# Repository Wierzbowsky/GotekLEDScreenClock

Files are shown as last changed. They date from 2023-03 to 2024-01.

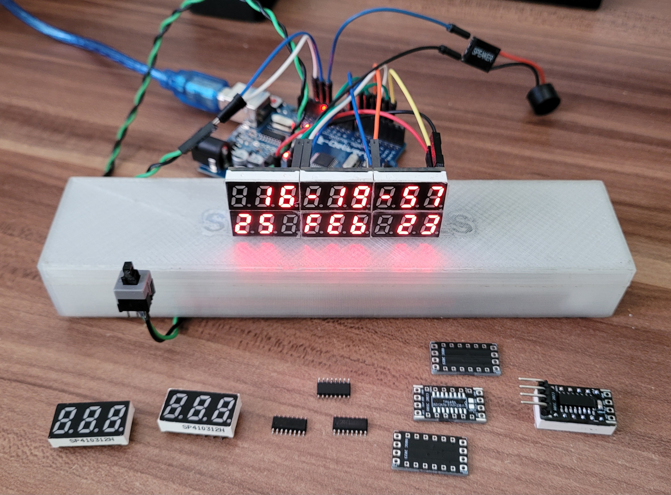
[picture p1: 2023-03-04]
Pics/20230225_162103.jpg

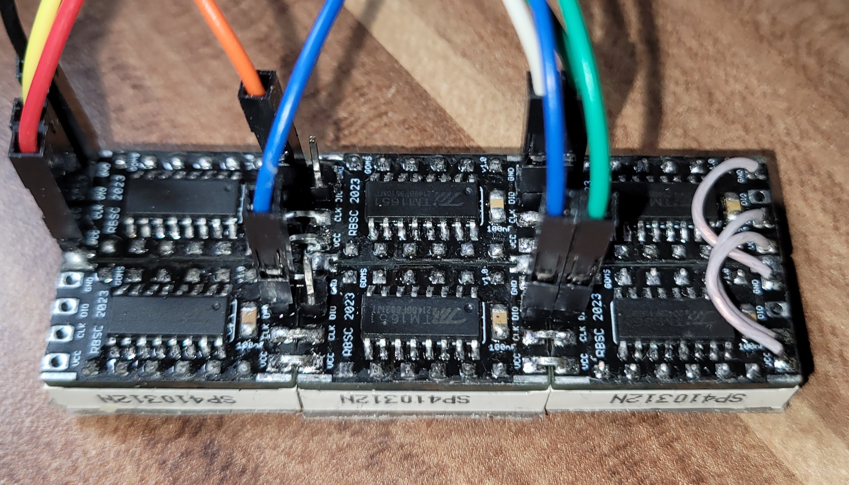
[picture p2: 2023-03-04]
Pics/20230304_183644.jpg

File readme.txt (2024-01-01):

--------------------------------------------------------------------------------
Clock with calendar from Gotek's LED screen parts
Copyright (c) 2022-2023 Wierzbowsky [RBSC]
Version 1.0.0006
--------------------------------------------------------------------------------

About
-----

This is the the self-made clock that was created from salvaged Gotek's 7-segment LED screen boards. The original Gotek
screen boards need to be dismantled and all parts (IC, screen, capacitor) are used to create a single or combined
indicator panel with the help of tiny circuit boards that can be joined together. These boards share all signals except
for DIO. Each DIO pin is connected to the corresponding pin of the Arduino Mini, Nano or Uno board. This particular clock
has 6 screens joined together.

The screens can display decimal and hexadecimal numbers with or without prepending zeroes, single digits and characters
at defined positions, all Latin alphabet and also several special characters (minus, plus, slash, etc). The original
Arduino library for the TM1651 chip created by Derek Cooper was almost completely rewritten and enriched with features.
A few subroutines from the library were imported into the .INO file to make things easier.

The Arduino board with the custom self-made firmware allows to set the time and date, select 3 brightness levels and also
to enable the auto-brightness mode. A user can enable the hourly beep during day hours and set the adjustment to slow
down or make the clock run faster. The total consumption of the clock with Arduino board is around 100mA, so powering it
up from a USB2 port is fine.

Assembling
----------

Take 6 orginal Gotek LED screen boards and desolder the LED screen, the controller chip and the capacitor. Then solder the
chip, capacitor and the screen onto the small board (you can order it from jlcpcb.com factory using the provided Gerber
files).

Solder a 4-pin single row header to the right side of one assembled board. To make it easier, it's recommended to solder
the 4-pin header BEFORE soldering the screen. Cut the popping out pins of the pin header from the other side so that the
screen could be fully set onto the board.

Assemble the 2-row 3-column display from the 6 complete boards. Make sure that there's no gap between the screens. To join
the boards you can use U shaped pins cut from the pin headers. See the picture of the assembled screen for reference.

Connect power, ground and clock lines of each screens in a row together. Solder 3 wires between corresponding solder pads
of power, ground and clock signals of the upper row and the bottom row. See the picture of the assembled screen.

Finally, solder four 2-pin headers onto the DIO solder pads of each board. 

Connections
-----------

Connect each board's DIO pin to the digitap I/O pin of the Arduino Uno or Nano board. Please note thet the board has DIO
pads on each side, so please connect only ONE of them (one DIO signal for each screen). Connecting the DIO pins should be
done in the specific order so that the pin the the smallest number is connected to the leftmost screen.

In my setup the DIO pins are connected to the Arduino board the following way:

-------------------------
|---3---|---4---|---5---|
-------------------------
|---6---|---7---|---8---|
-------------------------

Connect the 3.3v power from the Arduino board to the 4-pin header's VCC pin. Connect the ground from the Arduino board to
the 4-pin header's GND pin. Connect the I/O pin 3 from the Arduino board to the 4-pin header's CLK pin (this is clock
signal). You can change the pin assignment in the source files if you wish. The current pin assignment is as follows:

Arduino		Clock board or beeper/button
--------------------------------------------
3.3v		VCC
GND		GND
 2		CLK
 3		DIO pin of screen 1
 4		DIO pin of screen 2
 5		DIO pin of screen 3
 6		DIO pin of screen 4
 7		DIO pin of screen 5
 8		DIO pin of screen 6
12		Beeper (optional)
13		Button
GND		Beeper's ground
GND             Button's ground

The piezo beeper is optional, but recommended. You can use a simple 2-pin beeper in a barrel-shaped case. It can be found
anywhere on AliExpress or Ebay. For example: https://www.ebay.com/itm/374210416844

Operation
---------

The clock is controlled by a single pushbutton. There are 3 types of commands that you can execute. A short pushdown (less
than 1 second push), a medium pushdown (over 1 second push) and a long pushdown (over 2 second push). It's all about timing.
Each operation is acknowledged by the clock with a beep of different frequency and duration if beep is enabled.

When the clock shows date and time, a short pushdown will change the brightness mode and disable the auto-brightness mode if
if was previously set. There are 3 different brightness levels to select manually. The auto-brightness uses only the dimmest
and the brightest levels.

The medium pushdown will allow to enter the settings mode (see below). The long pushdown switches on the auto-brightness
mode. The brightness will automatically change based on time of the day. From 8:00 to 20:00 high brightness is set,
otherwise low brightness is set.

The settings option can be selected by holding the pushbutton for over 1 second. In the settings mode a short pushdown will
change the value of hour, minute, second (reset to zero), day, month, year, select beep ON or beep OFF, select auto-brightness
ON of OFF, as well as allow to set the clock speed adjustment in the range of -15 to 15 (slow/fast). A short pushdown will
zero the value of seconds if seconds are blinking, for other values it will either switch them between ON or OFF or advance
the setting by 1. The medium pushdown will allow to select the setting that needs to be changed (hour, minute, day, etc.).
The currently selected value will blink. The selection is done in a loop, for example: second->minute->hour->second. The long
pushdown will switch to the next setup screen. That last screen of the setup will ask to press a button to start the clock
with the selected settings. The following setup screens are available in version 1.0.0005:

-> Set time -> Set date -> Set auto-brightness -> Set beep -> Set adjust -> Start clock

It may be tricky to change settings for the first time, but you will get used to it pretty fast.

Operation and test videos
-------------------------

You can see the videos of the clock's testing on Youtube:

 - https://www.youtube.com/watch?v=1-ujJE8o4cY
 - https://www.youtube.com/watch?v=EFognT4_trQ

IMPORTANT!
----------

I provide all files and information for free, without any liability (see the disclaimer.txt file). The provided information,
software or hardware must not be used for commercial purposes unless permitted by the owner. Producing a small amount of
bare boards for personal projects and selling the rest of the batch is allowed without the permission.

When the sources files are used to create alternative projects, please always mention the original source and the copyright!

Contact information
-------------------

The members of RBSC group Tnt23, Wierzbowsky, Pyhesty, Ptero, GreyWolf, SuperMax, VWarlock and DJS3000 can be contacted via the group's e-mail
address:

info@rbsc.su

The group's coordinator could be reached via this e-mail address:

admin@rbsc.su

The group's website can be found here:

https://rbsc.su/
https://rbsc.su/ru

The RBSC's hardware repository can be found here:

https://github.com/rbsc

The RBSC's 3D model repository can be found here:

https://www.thingiverse.com/groups/rbsc/things

-= ! MSX FOREVER ! =-

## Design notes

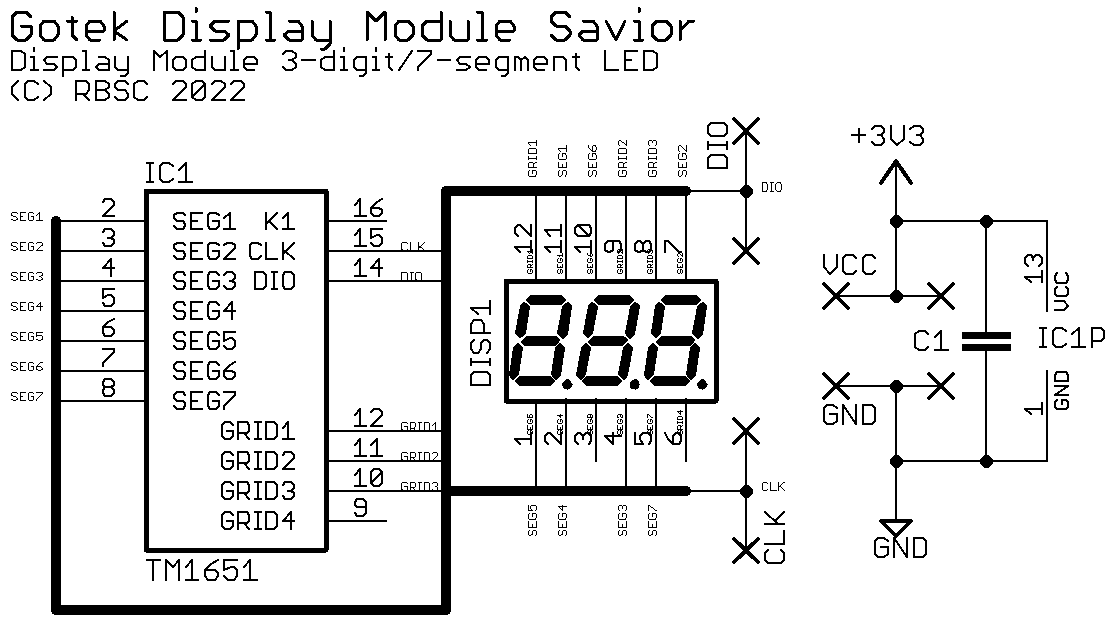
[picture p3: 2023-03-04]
Docs/schematics.png

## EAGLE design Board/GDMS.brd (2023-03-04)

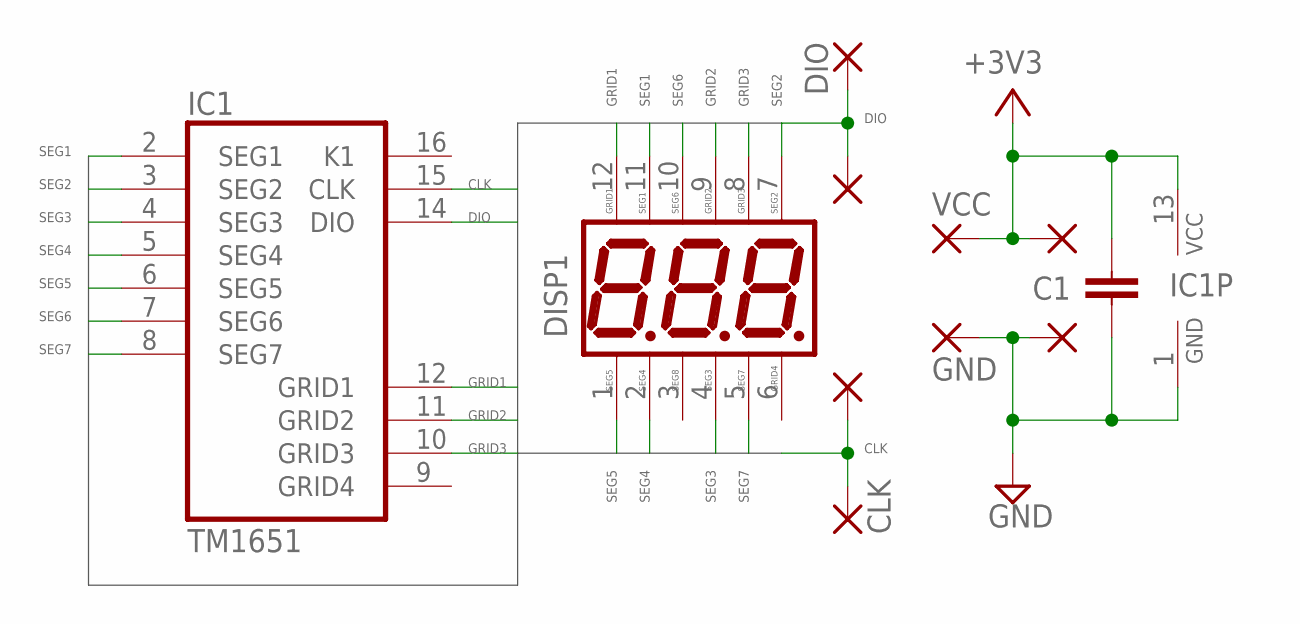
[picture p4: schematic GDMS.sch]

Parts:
C1: 100nF; C0805
DIS1: SP410312N; 3D7SEG
IC1: TM1651; SO16
P1: VCC; PADTH
P2, P4, P8, P9: PADTH
P3: GND; PADTH
P7: CLK; PADTH
P10: DIO; PADTH

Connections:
+3V3: C1.1, IC1.13 (VCC), P1.1, P2.1
CLK: IC1.15 (CLK), P7.1, P8.1
DIO: IC1.14 (DIO), P9.1, P10.1
GND: C1.2, IC1.1 (GND), P3.1, P4.1
GRID1: DIS1.12 (GRID1), IC1.12 (GRID1)
GRID2: DIS1.9 (GRID2), IC1.11 (GRID2)
GRID3: DIS1.8 (GRID3), IC1.10 (GRID3)
SEG1: DIS1.11 (SEG1), IC1.2 (SEG1)
SEG2: DIS1.7 (SEG2), IC1.3 (SEG2)
SEG3: DIS1.4 (SEG3), IC1.4 (SEG3)
SEG4: DIS1.2 (SEG4), IC1.5 (SEG4)
SEG5: DIS1.1 (SEG5), IC1.6 (SEG5)
SEG6: DIS1.10 (SEG6), IC1.7 (SEG6)
SEG7: DIS1.5 (SEG7), IC1.8 (SEG7)

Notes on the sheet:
DISP1

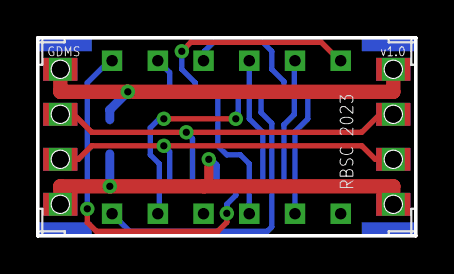
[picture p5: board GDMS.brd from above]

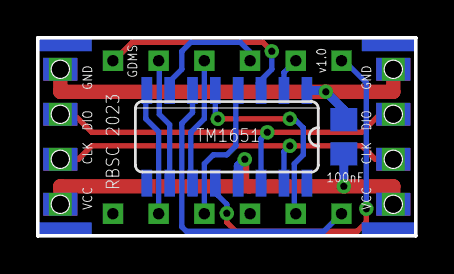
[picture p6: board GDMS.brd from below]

Board: 2 copper layers, 21.0 x 11.0 mm, 11 parts (2 on the bottom side), 14 nets.

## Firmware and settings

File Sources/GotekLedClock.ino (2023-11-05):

//****************************************************************
// GOCLOCK (Gotek Clock)
// Clock/calendar based on salvaged Gotek LED board with TM1651 chip
//
// Author:	  Alex Wierzbowsky
// Mail:	  	wierzbowsky@rbsc.su
// Hardware:	Re-used Gotek 3-digit LED screens on custom boards
// Board:   	Arduino Nano
// IDE:       Arduino
// Function:	Clock and calendar
// Date:		  06.11.2023
// Version:   1.0 Build 0007
// IDE:       Arduino-2.2.1
//
// Portions:  Paul Brace - Feb 2021
//
// Portions:  Detlef Giessmann Germany 
// Mail:      derek_cooper@hotmail.com
// Comment:   Library to drive LEDC68 Gotek 3 digit LED display
// IDE:       Arduino-1.8.12
//
//****************************************************************

//#include <SoftwareSerial.h>
//#include <Wire.h>
#include "GotekSaver.h"

// Define pins
#define Btnpin 10   // button pin
#define Buzzpin 9   // buzzer pin
#define Clockpin 2  // clock pin
#define Maxchars 9  // max characters on a display
#define Dispchars 3 // width of display

// Variables
uint8_t hour;
uint8_t minute;
uint8_t second;
uint8_t millisecond;
uint8_t date;
uint8_t month;
uint8_t year;
uint8_t currentbrt, changebrt;      // Brightness and change brightness control
uint8_t beep;
uint8_t autobrt;
signed long adjust;                 // ADJUST for inaccurate Arduino's clock, multiplied and added/deducted every minute
signed long multiplier;             // MULTIPLIER for clock adjust
volatile unsigned long currentTime, currentMode;     // Duration in milliseconds from midnight; currentMode: 1 when time/date is set; 0 - clock is running
unsigned long elapsed, timer;
unsigned long pushdelay;
char buffer[Maxchars+2];


//******************************************
// Setup
//
void setup()
{
// Set up time interrupt - millis() rolls over after 50 days so
// we are using our own millisecond counter which we can reset at
// the end of each day
 TCCR0A = (1 << WGM01);        //Set the CTC mode Compare time and trigger interrupt
 OCR0A = 0xF9;                 //Set value for time to compare to ORC0A for 1ms = 249  (8 bits so max is 256)
//[(Clock speed/Prescaler value)*Time   in seconds] - 1
//[(16,000,000/64) * .001] - 1 = 249 = 1 millisecond
 TIMSK0   |= (1 << OCIE0A);    //set timer compare interrupt
 TCCR0B |= (1 << CS01);        //Set the prescale 1/64 clock
 TCCR0B |= (1 << CS00);        // ie 110 for last 3 bits
 TCNT0  = 0;                   //initialize counter value to 0
 sei();                        //Enable   interrupt

 pinMode(Clockpin,OUTPUT);
 pinMode(Buzzpin,OUTPUT);
 pinMode(Btnpin,INPUT_PULLUP);

 for(Datapin = 3; Datapin < 9; Datapin++)
 {
  pinMode(Datapin,OUTPUT);
  displayOn();
  displaySet(currentbrt);
 }

 // Defaults
 hour=0;
 minute=0;
 second=0;

 date=06;
 month=11;
 year=23;

 // Variables
 multiplier = 10;
 pushdelay = 0;
 currentMode = 0;
 beep = 0;
 autobrt = 0;
 adjust = 0;
 currentbrt = 0;
 changebrt = 0;
 
 // Print version
 sprintf(buffer, " GOCLOCK ");
 Datapin = 5;
 PrintLine();
 sprintf(buffer, " 1-0 0007");
 Datapin = 8;
 PrintLine();
 //delay(3000);

 timer = currentTime;
 while(1)
 {
  elapsed = currentTime - timer;
  if (elapsed >= 3000) break;
 }

 for (Datapin = 4; Datapin < 9; Datapin++) displayClear();
 DisplayTime();
 DisplayDate();
 timer = currentTime = 0;
 currentMode = 0;
 interrupts();
}

//******************************************
//
// This is interrupt is called when   the compare time has been reached
// hence will be called once a millisecond   based on the
// OCR0A register setting.
ISR(TIMER0_COMPA_vect) {
  if (!currentMode) currentTime++;
}


//******************************************
// MAIN LOOP
//
void loop()
{
 int result;

 // Main control loop
 timer = currentTime;
 while(1)
 {
  elapsed = currentTime - timer;
  if (elapsed >= 1000)
  {
   timer = currentTime;
   ClockTick();       // Once per second
   DisplayTime();
   DisplayDate();
  }

  delay(50);
  if (result = ButtonCheck())
  {
   switch(result)
   {
    case 1:
    {
     autobrt = 0;
     changebrt = 0;
     if (beep) tone(Buzzpin,3000,100);
     if (currentbrt == 7) currentbrt = 0;
     else if (currentbrt == 0) currentbrt = 2;
     else if (currentbrt == 2) currentbrt = 7;
     for(Datapin = 3; Datapin < 9; Datapin++) displaySet(currentbrt);
     DisplayTime();
     DisplayDate();
     break;
    }
    case 2:
    {
     if (beep) tone(Buzzpin,3000,250);
     MainSetup();
     break;
    }
    case 3:
    {
     if (beep) tone(Buzzpin,5000,100);
     autobrt = 1;                       // Auto-control brightness
     changebrt = 1;
     break;
    }
    default:
     break;
   }
  }
 }
}

//******************************************
// Main setup
//
void MainSetup(void)
{
 uint16_t cnt;
 uint8_t shift;
 uint8_t param = 0;
 uint8_t set = 0;
 int result;
 uint8_t leapyear=0;

 // Adjust time
 Datapin=4;
 displaySpChar(0,Space);
 Datapin=5;
 displaySpChar(0,Space);
 
 sprintf(buffer, " SET TIME");
 Datapin = 8;
 PrintLine();
 Datapin=4;
 displaySpChar(0,Space);
 Datapin=5;
 displaySpChar(0,Space);

 param = 0;
 Datapin = 5;
 cnt = 0;
 while(!set)
 {
  delay(100);
  if (result = ButtonCheck())
  {
   switch(result)
   {
    case 1:
    {
     if (beep) tone(Buzzpin,3000,50);
     if (!param) second = 0;
     else if (param == 1)
     {
      minute++;
      if (minute == 60) minute = 0;
     }
     else if (param == 2)
     {
      hour++;
      if (hour == 24) hour = 0;
     }
     cnt = 1000;
     break;
    }
    case 2:
    {
     if (beep) tone(Buzzpin,3000,150);
     param++;
     if (param > 2) param = 0;
     cnt = 1000;
     break;
    }
    case 3:
    {
     if (beep) tone(Buzzpin,3000,250);
     set = 1;
     break;
    }    
   }
  }
  cnt++;
  if (cnt == 500)
  {
   Datapin = 5 - param;
   displayClear();
  }
  else if (cnt >= 1000)
  {
   DisplayTime();
   cnt = 0;
  }
 }
 DisplayTime();
 DisplayDate();

 // Adjust date
 sprintf(buffer, " SET DATE");
 Datapin = 5;
 PrintLine();

 param = 0;
 Datapin = 8;
 cnt = 0;
 set = 0;
 while(!set)
 {
  delay(100);
  if (result = ButtonCheck())
  {
   switch(result)
   {
    case 1:
    {
     if (beep) tone(Buzzpin,3000,50);
     if (!param)
     {
      year++;
      if (year > 50) year = 20;
     }
     else if (param == 1)
     {
      month++;
      if (month == 13) month = 1;
     }
     else if (param == 2)
     {
      if (year%4==0 and ((year%400==0) or (year%100!=0))) leapyear=1;
      if ((month==4 or month==6 or month==9 or month==11) and date==30) date=1;
      else if (month==2 and ((leapyear==0 and date==28) or (leapyear==1 and date==29))) date=1;
      else date++;
      if (date==32) date=1;
     }
     cnt = 1000;
     break;
    }
    case 2:
    {
     if (beep) tone(Buzzpin,3000,150);
     param++;
     if (param > 2) param = 0;
     cnt = 1000;
     break;
    }
    case 3:
    {
     if (beep) tone(Buzzpin,3000,250);
     set = 1;
     break;
    }    
   }
  }
  cnt++;
  if (cnt == 500)
  {
   Datapin = 8 - param;
   displayClear();
  }
  else if (cnt >= 1000)
  {
   DisplayDate();
   cnt = 0;
  }
 }

 // Auto brightness
 sprintf(buffer, " AUTO BRT");
 Datapin = 5;
 PrintLine();
 if (autobrt) sprintf(buffer, "       ON");
 else sprintf(buffer, "      OFF");
 Datapin = 8;
 PrintLine(); 

 cnt = 0;
 set = 0;
 while(!set)
 {
  delay(100);
  if (result = ButtonCheck())
  {
   switch(result)
   {
    case 1:
    {
     if (beep) tone(Buzzpin,3000,50);
     if (!autobrt) autobrt = 1;
     else autobrt = 0;
     cnt = 1000;     
     break;
    }
    case 3:
    {
     if (beep) tone(Buzzpin,3000,250);
     set = 1;
     break;
    }    
   }
  }
  cnt++;
  if (cnt == 500)
  {
   Datapin = 8;
   displayClear();
  }
  else if (cnt >= 1000)
  {
   if (autobrt) sprintf(buffer, "       ON");
   else sprintf(buffer, "      OFF");
   Datapin = 8;
   PrintLine(); 
   cnt = 0;
  }
 }

 // Adjust beep
 sprintf(buffer, " SET BEEP");
 Datapin = 5;
 PrintLine();
 if (beep) sprintf(buffer, "       ON");
 else sprintf(buffer, "      OFF");
 Datapin = 8;
 PrintLine(); 
 
 cnt = 0;
 set = 0;
 while(!set)
 {
  delay(100);
  if (result = ButtonCheck())
  {
   switch(result)
   {
    case 1:
    {
     if (beep) tone(Buzzpin,3000,50);
     if (!beep) beep = 1;
     else beep = 0;
     cnt = 1000;     
     break;
    }
    case 3:
    {
     if (beep) tone(Buzzpin,3000,250);
     set = 1;
     break;
    }    
   }
  }
  cnt++;
  if (cnt == 500)
  {
   Datapin = 8;
   displayClear();
  }
  else if (cnt >= 1000)
  {
   if (beep) sprintf(buffer, "       ON");
   else sprintf(buffer, "      OFF");
   Datapin = 8;
   PrintLine(); 
   cnt = 0;
  }
 }
 
 // Set adjust
 sprintf(buffer, "   ADJUST");
 Datapin = 5;
 PrintLine();
 if (adjust >= 0) sprintf(buffer, "      %03d", adjust);
 else sprintf(buffer, "     -%03d", adjust);
 Datapin = 8;
 PrintLine(); 
 
 cnt = 0;
 set = 0;
 while(!set)
 {
  delay(100);
  if (result = ButtonCheck())
  {
   switch(result)
   {
    case 1:
    {
     currentMode = 1; // stop count
     if (beep) tone(Buzzpin,3000,50);
     adjust++;
     if (adjust > 15) adjust = -15;
     cnt = 1000;
     currentMode = 0; // resume count
     break;
    }
    case 3:
    {
     if (beep) tone(Buzzpin,3000,250);
     set = 1;
     break;
    }    
   }
  }
  cnt++;
  if (cnt == 500)
  {
   Datapin = 8;
   displayClear();
  }
  else if (cnt >= 1000)
  {
   if (adjust >= 0) sprintf(buffer, "      %03d", adjust);
   else sprintf(buffer, "     -%03d", abs(adjust));
   Datapin = 8;
   PrintLine(); 
   cnt = 0;
  }
 }

 // Press button to start clock
 sprintf(buffer, "    PRESS");
 Datapin = 5;
 PrintLine();
 sprintf(buffer, " TO START");
 Datapin = 8;
 PrintLine();

 cnt = 0;
 set = 0;
 while(!set)
 {
  delay(100);
  if (result = ButtonCheck())
  {
    break;
  }
  cnt++;
  if (cnt == 500)
  {
    for (Datapin = 4; Datapin < 9; Datapin++) displayClear();
  }
  else if (cnt >= 1000)
  {
    sprintf(buffer, "    PRESS");
    Datapin = 5;
    PrintLine();
    sprintf(buffer, " TO START");
    Datapin = 8;
    PrintLine();
    cnt = 0;
  }
 }
 timer = currentTime = 0; 
 currentMode = 0; // Normal mode
 DisplayTime();
 DisplayDate();
 if (beep) tone(Buzzpin,5000,100);
}


//******************************************
// Prints a text line on a display from buffer
// Set Datapin for rightmost screen's pin number
//
void PrintLine()
{
 uint16_t cnt;
 uint8_t shift;

 shift = Maxchars-1;
 for(cnt = 0; cnt < Dispchars; cnt++)
 {
  displayChar(0, buffer[shift-2]);
  displayChar(1, buffer[shift-1]);
  displayChar(2, buffer[shift]);
  Datapin--;
  shift = shift - Dispchars;
 }
}

//******************************************
// Display time
//
void DisplayTime()
{
 uint8_t cnt;
 uint8_t shift;

 sprintf(buffer, " %02d %02d %02d",hour,minute,second);
 Datapin = 5;
 PrintLine();

 // Pulse dashes in clock
 if (second%2)
 {
  Datapin=4;
  displaySpChar(0,Minus);
  Datapin=5;
  displaySpChar(0,Minus);
 }
 else
 {
  Datapin=4;
  displaySpChar(0,Space);
  Datapin=5;
  displaySpChar(0,Space);
 }
}

//******************************************
// Display date
//
void DisplayDate()
{
 char monthname[4];
 uint8_t cnt;
 uint8_t shift;

 for(cnt = 0; cnt < 3; cnt++) monthname[cnt] = MonthTab[cnt + ((month - 1) * 3)];
 monthname[3] = '\0';
 if (date > 9) sprintf(buffer, "%02d %s %02d",date,monthname,year);
 else sprintf(buffer, " %d %s %02d",date,monthname,year);
 Datapin = 8;
 PrintLine();
}

//******************************************
// Checks for keypress (short, long, very long)
//
int ButtonCheck(void)
{
 if (digitalRead(Btnpin) == LOW) pushdelay++;
 if (pushdelay > 0 and digitalRead(Btnpin) == HIGH)
 {
  if ((pushdelay <= 500))
  {
    pushdelay = 0;
    return 1; // short press
  }
  else if (pushdelay <= 1000)
  {
    pushdelay = 0;
    return 2;  // long press
  }
  else if (pushdelay <= 3000)
  {
    pushdelay = 0;
    return 3;  // very long press
  }
  else
  {
   pushdelay = 0;
   return 0;
  }
 }
 else return 0;
}

//******************************************
// Clock adjust every hour
//
void ClockAdjust()
{
  if (adjust != 0)
  {
    currentMode = 1;
    if (adjust < 0)
    {
      if (currentTime >= abs(adjust) * multiplier) currentTime = currentTime - abs(adjust) * multiplier;
      else delay(abs(adjust) * multiplier);
    }
    else if (adjust > 0) currentTime = currentTime + abs(adjust) * multiplier;
    currentMode = 0;
  }
}

//******************************************
// Clock tick (every 1000ms)
//
void ClockTick()
{
 // Clock advance by 1 second
 second++;
 if (second==60)
 {
  second=0;
  minute++;
  ClockAdjust();    // Adjust clock every defined interval

  // Check if auto-brightness mode is on
  if (autobrt and changebrt)
  {
   for(Datapin = 3; Datapin < 9; Datapin++)
   {
    if (hour > 9 and hour < 18)
    {
     currentbrt = 7;
     displaySet(currentbrt);
    }
    else
    {
     currentbrt = 0;
     displaySet(currentbrt);
    }
   }
   changebrt = 0;
  }
  
  if (minute==60)
  {
   minute=0;
   hour++;
   if (beep and (hour >= 8 and hour <= 20)) tone(Buzzpin,3000,50); // beep every hour during daytime if on
   if (hour==24)
   {
     hour=0;
     currentMode = 1;
     timer = currentTime = 0; // Reset counter daily
     currentMode = 0;
     DateTick();
   }
  }
 }
}

//******************************************
// Date tick (every 24h)
//
void DateTick()
{
 uint8_t leapyear=0;
 
 if (year%4==0 and ((year%400==0) or (year%100!=0))) leapyear=1;
 if ((month==4 or month==6 or month==9 or month==11) and date==30)
 {
  date=1;
  month++;
 }
 else if (month==2 and ((leapyear==0 and date==28) or (leapyear==1 and date==29)))
 {
  date=1;
  month++;
 }
 else date++;
 if (date==32)
 {
  date=1;
  month++;
 }
 if (month==13)
 {
  date=1;
  month=1;
  year++;
 }
 DisplayDate();
}

//******************************************
// Write byte to chip
//
int writeByte(int8_t wr_data)
{
  uint8_t i,count1;       
  for(i=0;i<8;i++)        //sent 8bit data
  { 
    digitalWrite(Clockpin,LOW);
    if (wr_data & 0x01)digitalWrite(Datapin,HIGH);//LSB first
    else digitalWrite(Datapin,LOW);
    wr_data >>= 1;
    digitalWrite(Clockpin,HIGH);
  
  }
  digitalWrite(Clockpin,LOW); //wait for the ACK
  digitalWrite(Datapin,HIGH);
  digitalWrite(Clockpin,HIGH);
  pinMode(Datapin,INPUT);
  
  bitDelay(); 
  uint8_t ack = digitalRead(Datapin);
  if (ack == 0)
  {  
     pinMode(Datapin,OUTPUT);
     digitalWrite(Datapin,LOW);
  }
  bitDelay();
  pinMode(Datapin,OUTPUT);
  bitDelay();
  
  return ack;
}

//******************************************
//send start signal to TM1651
//
void start(void)
{
  digitalWrite(Clockpin,HIGH);//send start signal to TM1637
  digitalWrite(Datapin,HIGH);
  digitalWrite(Datapin,LOW);
  digitalWrite(Clockpin,LOW);
} 

//******************************************
//End signal
//
void stop(void)
{
  digitalWrite(Clockpin,LOW);
  digitalWrite(Datapin,LOW);
  digitalWrite(Clockpin,HIGH);
  digitalWrite(Datapin,HIGH);
}

//******************************************
// Display hexadecimal number 0-F at selected position
//
void displayNum(uint8_t dig, uint8_t number)
{
  start();          //start signal sent to TM1651 from MCU
  writeByte(ADDR_FIXED);//
  stop();           //
  start();          //
  writeByte(STARTADDR + dig);// digit pos 0-2
  writeByte(NumTab[number]);//
  stop();            //
  start();          //
  writeByte(Cmd_DispCtrl);// 88+0 to 7 brightness, 88=display on
  stop();           //
}

//******************************************
// Clear display (no numbers lit)
//
void displayClear(void)
{
 displayDP(0);
 displayNum(0,16);
 displayNum(1,16);
 displayNum(2,16);
}

//******************************************
// Show 3 zeroes on display
//
void displayZero(void)
{
 displayDP(0);
 displayInteger(0);
}

//******************************************
// Set brightness
//
void displaySet(uint8_t brightness)
{
  Cmd_DispCtrl = 0x88 + brightness;	//Set the brightness and turn on
}

//******************************************
// Switch off display
//
void displayOff()
{
  Cmd_DispCtrl = 0x80;
  start();
  writeByte(Cmd_DispCtrl);	// 80=display off
  stop();
}

//******************************************
// Init display
//
void displayOn()
{
 displayClear();
 displayDP(0);
 displaySet(currentbrt);
}

//******************************************
// Small delay
//
void bitDelay(void)
{
 delayMicroseconds(50);
}

//******************************************
// Display characters 0-9, A-Z, space in a defined position (letters must be in uppercase!)
//
void displayChar(uint8_t dig, uint8_t letter)
{
  start();          //start signal sent to TM1651 from MCU
  writeByte(ADDR_FIXED);//
  stop();           //
  start();          //
  writeByte(STARTADDR + dig);// digit pos 0-2
  if (letter >= 'A' and letter <= 'Z') writeByte(CharTab[letter - 0x41]);  // A-Z
  else if (letter >='0' and letter <= '9') writeByte(NumTab[letter - 0x30]); // 0-9
  else if (letter =='-') writeByte(SpCharTab[2]); // -
  else writeByte(NumTab[16]);  // space
  stop();            //
  start();          //
  writeByte(Cmd_DispCtrl);// 88+0 to 7 brightness, 88=display on
  stop();           //
}

//******************************************
// Display special character (see definitions)
//
void displaySpChar(uint8_t dig, uint8_t letter)
{
  start();          //start signal sent to TM1651 from MCU
  writeByte(ADDR_FIXED);//
  stop();           //
  start();          //
  writeByte(STARTADDR + dig);// digit pos 0-2
  writeByte(letter);//
  stop();            //
  start();          //
  writeByte(Cmd_DispCtrl);// 88+0 to 7 brightness, 88=display on
  stop();           //
}

//******************************************
// Display decimal number 0-999 with prepended zeroes
//
void displayDec(uint16_t num)
{
  displayNum(0, (num/10/10) % 10);
  displayNum(1, (num/10) % 10);
  displayNum(2, num % 10);
}

//******************************************
// Display decimal number 0-999 without prepended zeroes
//
void displayDecNZ(uint16_t num)
{
  if (num > 99) displayNum(0, (num/10/10) % 10);
  if (num > 9) displayNum(1, (num/10) % 10);
  displayNum(2, num % 10);
}

//******************************************
// Display decimal number 0-99 with one zero
//
void displayDec1Z(uint16_t num)
{
  if (num > 99) displayNum(0, (num/10/10) % 10);
  displayNum(1, (num/10) % 10);
  displayNum(2, num % 10);
}

//******************************************
// Display dot (doesn't work on all displays)
//
void displayDP(uint8_t dp)
{
  uint8_t SegData;

  //if (dp == 1) SegData = 0x08;
  //else SegData = 0x00;
  start();          //start signal sent to TM1651 from MCU
  writeByte(ADDR_FIXED);
  stop();  
  start();
  writeByte(STARTADDR + 3);// digit pos 3 controls decimal point
  //writeByte(SegData);
  writeByte(dp);
  stop();      
  start();  
  writeByte(Cmd_DispCtrl);// 88+0 to 7 brightness, 88=display on
  stop();  
}

//******************************************
// Display hex number 0-FFF (4095)
//
void displayHex(uint16_t num)
{
 if (num > 0xFFF)
 {
  displaySpChar(0, Minus);
  displaySpChar(1, Minus);
  displaySpChar(2, Minus);
 }
 else
 { 
  displayNum(0, (num/16/16) % 16);
  displayNum(1, (num/16) % 16);
  displayNum(2, num % 16);
 }
}

void displayHexNZ(uint16_t num)
{
 if (num > 0xFFF)
 {
  displaySpChar(0, Minus);
  displaySpChar(1, Minus);
  displaySpChar(2, Minus);
 }
 else
 { 
  if (num > 0xFF) displayNum(0, (num/16/16) % 16);
  if (num > 0x0F) displayNum(1, (num/16) % 16);
  displayNum(2, num % 16);
 }
}

//******************************************
// Display decimal number 0-999 with prepended zeroes
//
void displayInteger(uint16_t number)
{
 uint8_t i;   

 if (number > 999)
 {
  displaySpChar(0, Minus);
  displaySpChar(1, Minus);
  displaySpChar(2, Minus);
 }
 else
 {
  start();          //start signal sent to TM1651 from MCU
  writeByte(ADDR_AUTO);// auto increment the address
  stop(); 
  start();
  writeByte(STARTADDR);// start at 0
   writeByte(NumTab[(number/100) % 10]);
   writeByte(NumTab[(number/10) % 10]);
   writeByte(NumTab[number % 10]);
  stop();
  start();
  writeByte(Cmd_DispCtrl);// 88+0 to 7 brightness, 88=display on
  stop();
 }
}

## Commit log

2023-03-04 Initial release 04.03.2023
    Initial release
    [GDMS.GBL, GDMS.GBO, GDMS.GBP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]
2023-10-09 Updated firmware
    Firmware has been updated for more precise clock adjustment, added title with version number and build, also added waiting for a button press to start the clock after adjustments.
2023-10-28 Updated to version 1.0.0005
    Added auto-brightness control. Beep setting is now global and off by default. Core was rewritten to prevent lockups.
    [GotekLedClock.ino]
2023-10-31 Version 1.00.0006
    More stable build, picture of the case added.
2023-11-05 Version 1.0.0007
    Decreased the multiplier's value for better clock correction precision
    [GotekLedClock.ino]
